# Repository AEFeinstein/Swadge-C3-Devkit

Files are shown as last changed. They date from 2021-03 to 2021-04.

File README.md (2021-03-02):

# Swadge-C3-Devkit

It's a Swadge devkit featuring:

* [ESP32-C3-MINI-1](https://www.espressif.com/sites/default/files/documentation/esp32-c3-mini-1_datasheet_en.pdf)
* [QMA6981 Accelerometer](https://datasheet.lcsc.com/szlcsc/QST-QMA6981_C310611.pdf)
* [0.96" 128x64 OLED Display](https://www.buydisplay.com/download/manual/ER-OLED0.96-1_Series_Datasheet.pdf)
* [Microphone](https://www.puiaudio.com/media/SpecSheet/POM-2738P-R.pdf)
* [Piezo Buzzer](https://datasheet.lcsc.com/szlcsc/1808301434_ZLFY-ZL-YDW1207-4005PA-5-0_C219727.pdf)
* 8x [WS2812b LEDs](https://cdn-shop.adafruit.com/datasheets/WS2812B.pdf)
* 8x [Tactile buttons](https://www.te.com/commerce/DocumentDelivery/DDEController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)
* 2x [AA Battery clips](http://www.keyelco.com/product-pdf.cfm?p=1025)
* [Micro USB Power](https://www.molex.com/pdm_docs/sd/473460001_sd.pdf)

It's compatible with the [Swadge Programmer](https://github.com/AEFeinstein/Super-2020-Swadge-HW/tree/master/hardware/swadge-programmer) used for ESP8266 based Swadges, though some GPIOs aren't broken out on the v2 programmer.

# 3D Render

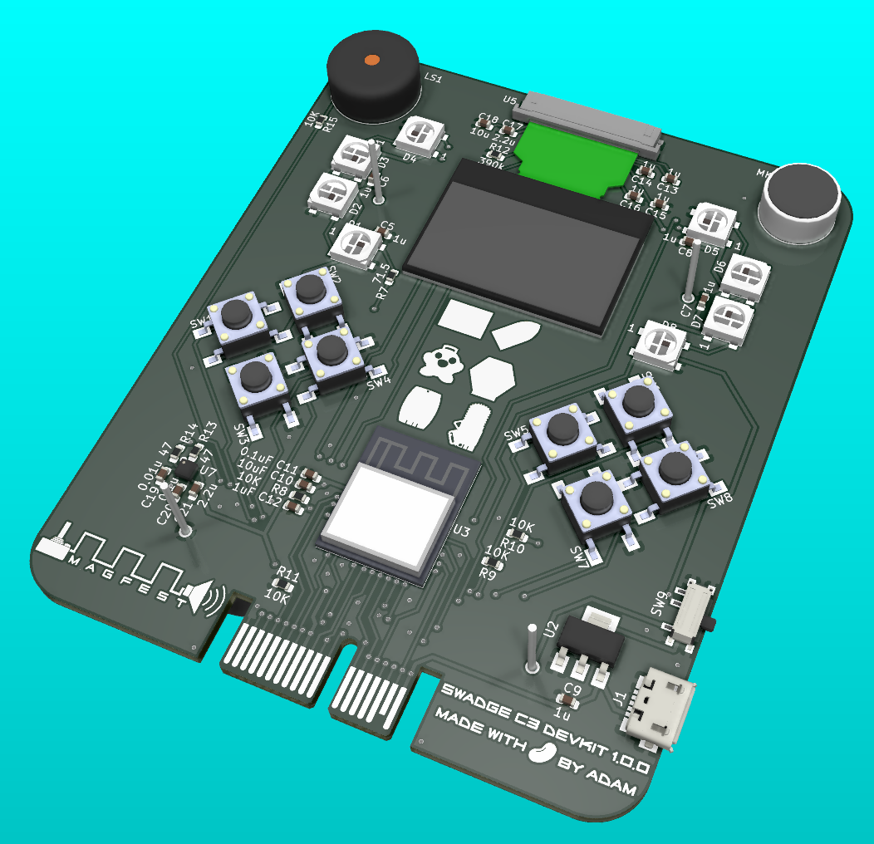
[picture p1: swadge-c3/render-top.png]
3D Render


# Schematic

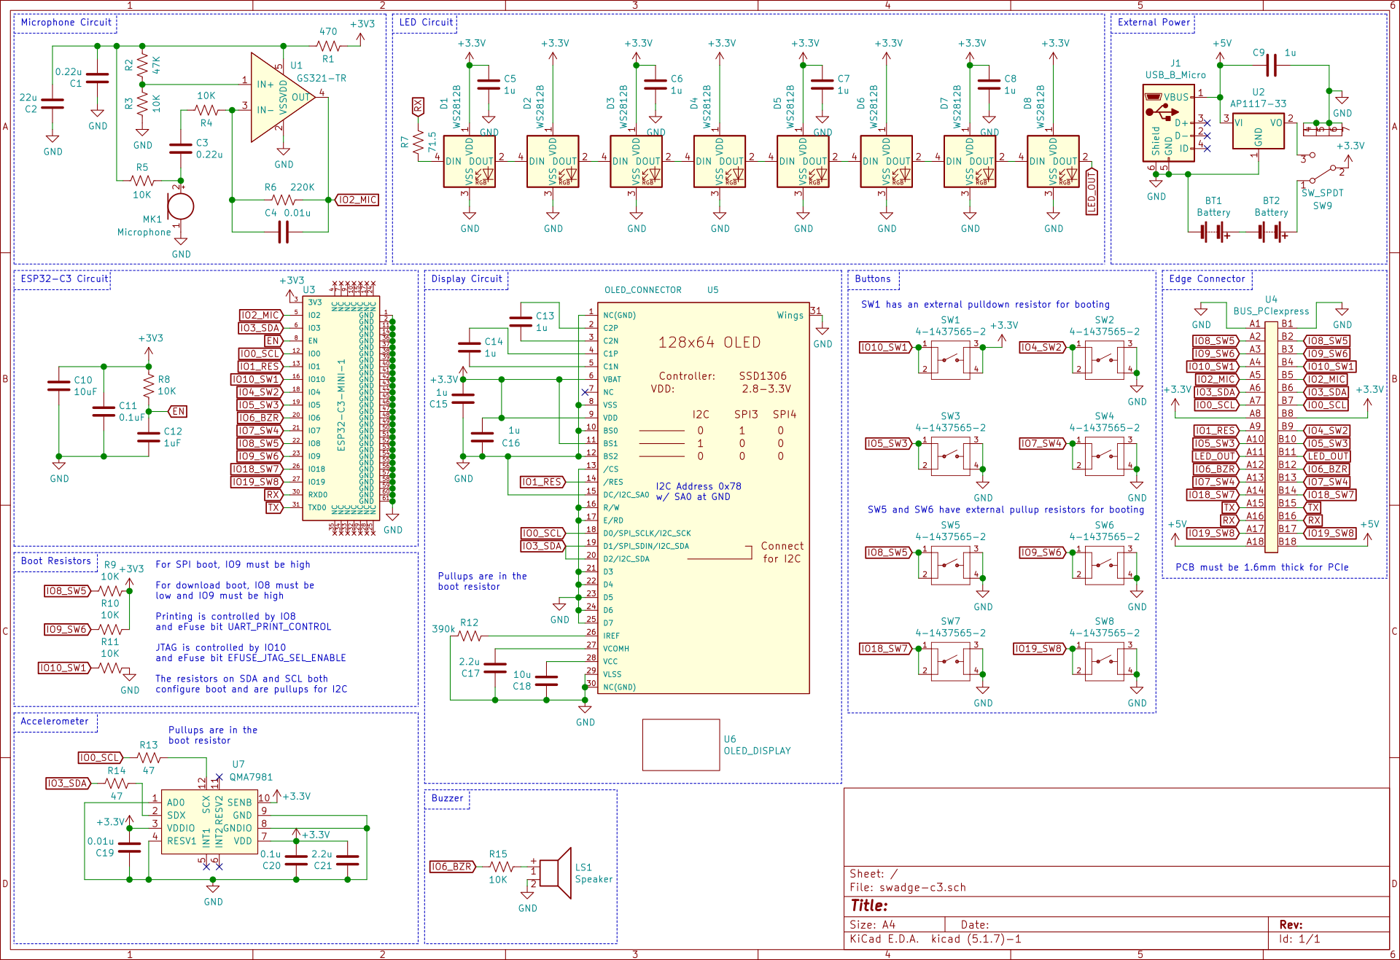
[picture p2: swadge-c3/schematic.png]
Schematic


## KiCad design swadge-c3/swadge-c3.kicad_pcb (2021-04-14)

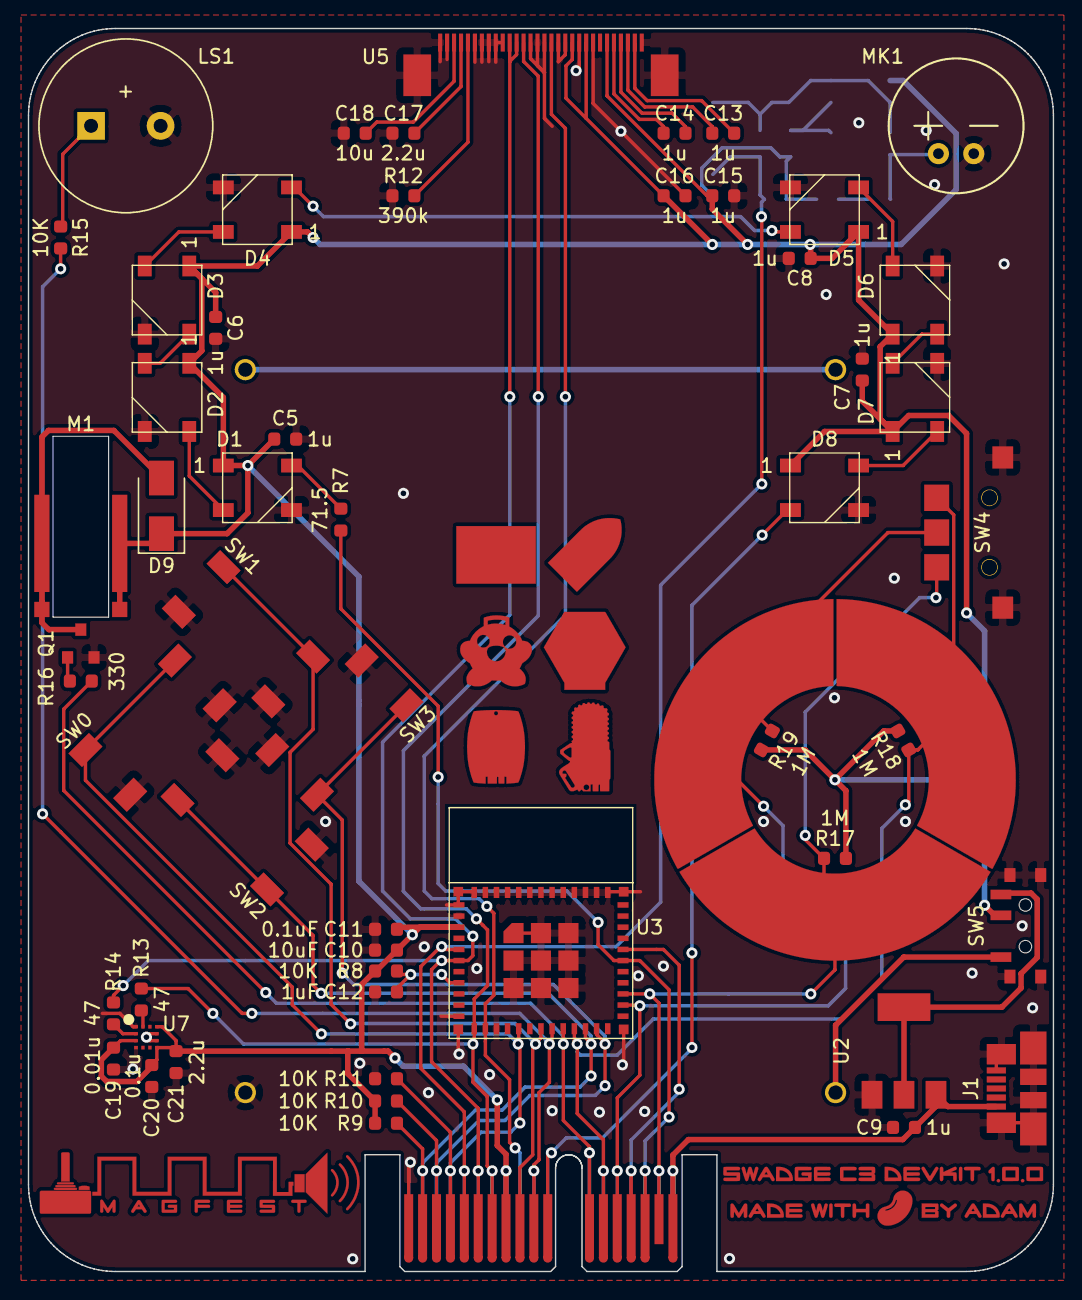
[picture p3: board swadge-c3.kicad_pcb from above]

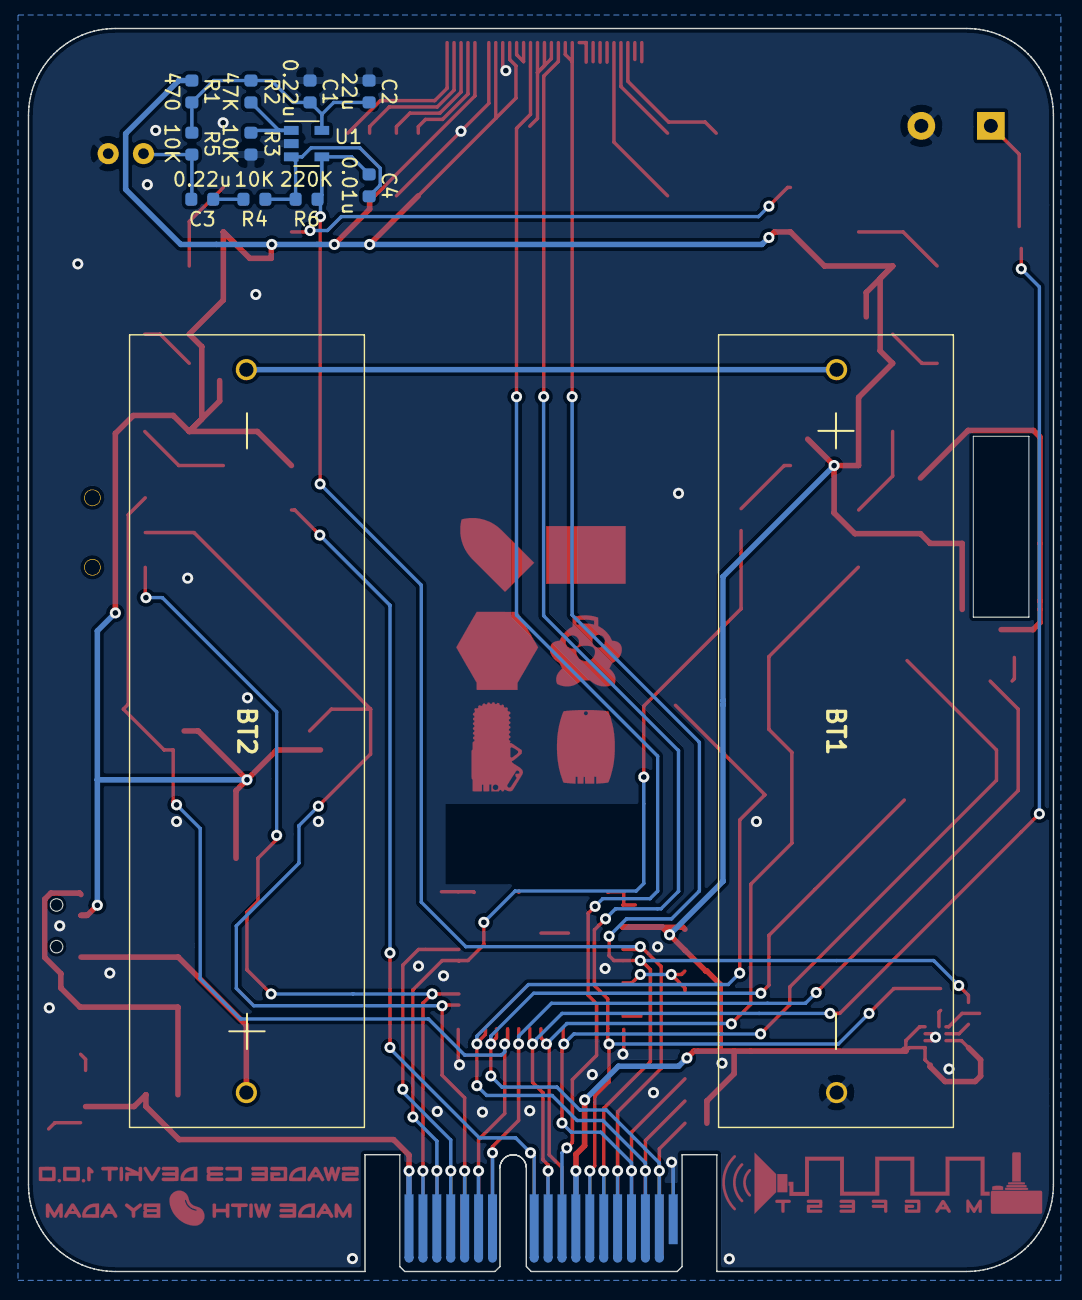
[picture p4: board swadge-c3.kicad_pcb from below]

Board: 2 copper layers, 73.7 x 89.4 mm, 73 parts (13 on the bottom side), 48 nets.

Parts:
BT1, BT2: Battery; 2460
C1, C3: 0.22u; C_0603_1608Metric
C2: 22u; C_0603_1608Metric
C4, C19: 0.01u; C_0603_1608Metric
C5, C6, C7, C8, C9, C13, C14, C15, C16: 1u; C_0603_1608Metric
C10: 10uF; C_0603_1608Metric
C11: 0.1uF; C_0603_1608Metric
C12: 1uF; C_0603_1608Metric
C17, C21: 2.2u; C_0603_1608Metric
C18: 10u; C_0603_1608Metric
C20: 0.1u; C_0603_1608Metric
D1, D2, D3, D4, D5, D6, D7, D8: WS2812B; LED_WS2812B_PLCC4_5.0x5.0mm_P3.2mm
D9: D; D_SMA
J1: USB_B_Micro; USB_Micro-B_Molex_47346-0001
LS1: Speaker; Buzzer_12.5x7.5
M1: Motor_DC; Z30C1B839982L
MK1: Microphone; CMA-4544PF-W
Q1: Q_NPN_BEC; SOT-23
R1: 470; R_0603_1608Metric
R2: 47K; R_0603_1608Metric
R3, R4, R5, R8, R9, R10, R11, R15: 10K; R_0603_1608Metric
R6: 220K; R_0603_1608Metric
R7: 71.5; R_0603_1608Metric
R12: 390k; R_0603_1608Metric
R13, R14: 47; R_0603_1608Metric
R16: 330; R_0603_1608Metric
R17, R18, R19: 1M; R_0603_1608Metric
SW0, SW1, SW2, SW3: 4-1437565-2; SW_4-1437565-2
SW4: LEVER8184
SW5: SW_SPDT; SW_SPDT_PCM12
TC1: touch-ring-3
U1: GS321-TR; SOT-23-5
U2: AP1117-33; SOT-223-3_TabPin2
U3: ESP32-C3-MINI-1; esp32-c2-mini-1
U4: BUS_PCIexpress
U5: OLED_CONNECTOR; ER-OLED0.96-1.3
U6: OLED_DISPLAY; NULL
U7: QMA7981; QMA6981
U8: art_made_by_adam; made-by-adam
U9: art_mag_logo_metal; mag-logo-metal
U10: art_swadge_family; swadges-family

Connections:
+3V3: C5.1, C6.1, C7.1, C8.1, C10.1, C11.1, C15.2, C16.2, C19.2, C20.2, C21.2, D1.1, D2.1, D3.1, D4.1, D5.1, D6.1, D7.1, D8.1, D9.1, M1.1, R1.1, R8.2, R9.1, R10.1, R17.2, R18.2, R19.2, SW5.2, U3.3, U4.A8, U4.B8, U5.6, U5.9, U5.11, U7.3, U7.7, U7.10
+5V: C9.2, J1.1, U2.3, U4.A18, U4.B18
EN: C12.1, R8.1, U3.8
GND: BT1.2, C1.1, C2.1, C5.2, C6.2, C7.2, C8.2, C9.1, C10.2, C11.2, C12.2, C15.1, C16.1, C17.1, C18.1, C19.1, C20.1, C21.1, D1.3, D2.3, D3.3, D4.3, D5.3, D6.3, D7.3, D8.3, J1.5, J1.6, LS1.2, MK1.1, Q1.2, R3.1, R11.1, R12.1, SW0.3, SW0.4, SW1.3, SW1.4, SW2.3, SW2.4, SW3.3, SW3.4, SW4.C, SW5.4, SW5.5, SW5.6, SW5.7, U1.2, U2.1, U3.1, U3.2, U3.11, U3.14, U3.36, U3.37, U3.38, U3.39, U3.40, U3.41, U3.42, U3.43, U3.44, U3.45, U3.46, U3.47, U3.48, U3.49, U3.50, U3.51, U3.52, U3.53, U3.54, U3.55, U3.56, U3.57, U3.58, U3.59, U3.60, U3.61, U4.A1, U4.B1, U5.1, U5.8, U5.10, U5.12, U5.13, U5.15, U5.16, U5.17, U5.21, U5.22, U5.23, U5.24, U5.25, U5.29, U5.30, U5.31, U7.1, U7.4, U7.8, U7.9
IO0_SCL: R13.2, U3.12, U4.A7, U4.B7, U5.18
IO1_RES: U3.13, U4.A9, U5.14
IO2_MIC: C4.1, R6.1, U1.4, U3.5, U4.A5, U4.B5
IO3_SDA: R14.2, U3.6, U4.A6, U4.B6, U5.19, U5.20
IO4_SW1: SW1.1, SW1.2, U3.18, U4.B9
IO5_BZR: R15.2, U3.19, U4.A10, U4.B10
IO6_VIB: R16.2, U3.20, U4.A12, U4.B12
IO7_TC0: R18.1, SW4.1, TC1.2, U3.21, U4.A13, U4.B13
IO8_SW2: R9.2, SW2.1, SW2.2, U3.22, U4.A2, U4.B2
IO9_SW3: R10.2, SW3.1, SW3.2, U3.23, U4.A3, U4.B3
IO10_SW0: R11.2, SW0.1, SW0.2, U3.16, U4.A4, U4.B4
IO18_TC1: R19.1, SW4.T, TC1.1, U3.26, U4.A14, U4.B14
IO19_TC2: R17.1, SW4.2, TC1.3, U3.27, U4.A17, U4.B17
LED_OUT: D8.2, U4.A11, U4.B11
unnamed: BT1.1, BT2.2
unnamed: BT2.1, SW5.1
unnamed: C1.2, C2.2, R1.2, R2.2, R5.1, U1.5
unnamed: C3.1, R4.2
unnamed: C3.2, MK1.2, R5.2
unnamed: C4.2, R4.1, R6.2, U1.3
unnamed: C13.1, U5.2
unnamed: C13.2, U5.3
unnamed: C14.1, U5.4
unnamed: C14.2, U5.5
unnamed: C17.2, U5.27
unnamed: C18.2, U5.28
unnamed: D1.2, D2.4
unnamed: D1.4, R7.1
unnamed: D2.2, D3.4
unnamed: D3.2, D4.4
unnamed: D4.2, D5.4
unnamed: D5.2, D6.4
unnamed: D6.2, D7.4
unnamed: D7.2, D8.4
unnamed: D9.2, M1.2, Q1.3
unnamed: LS1.1, R15.1
unnamed: Q1.1, R16.1
unnamed: R2.1, R3.2, U1.1
unnamed: R12.2, U5.26
unnamed: R13.1, U7.12
unnamed: R14.1, U7.2
unnamed: SW5.3, U2.2
RX: R7.2, U3.30, U4.A16, U4.B16
TX: U3.31, U4.A15, U4.B15

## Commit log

2021-02-26 Added CAD model for ESP32-C3-MINI-1
    [swadge-c3.kicad_pcb]
2021-02-26 Updated schematic
    [swadge-c3.kicad_pcb, swadge-c3.sch]
2021-02-27 Edited schematic, started layout
    [swadge-c3.kicad_pcb, swadge-c3.sch]
2021-02-27 layout updates
    [swadge-c3.kicad_pcb, swadge-c3.sch]
2021-03-01 Update layout
    [swadge-c3.kicad_pcb]
2021-03-01 Complete PCB routing
    [swadge-c3.kicad_pcb]
2021-03-01 Rounded corners
    [swadge-c3.kicad_pcb]
2021-03-01 Fix alignment
    [swadge-c3.kicad_pcb]
2021-03-02 Added art, renders, exported schematic
    [swadge-c3.kicad_pcb]
2021-03-02 Use correct schematic
2021-03-02 Replace SVG schematic with PNG
2021-03-02 Replaced QMA6981 with QMA7981. Updated art. Updated renders
    [swadge-c3.kicad_pcb, swadge-c3.sch]
2021-03-07 Added three way thumbswitch
    [swadge-c3.kicad_pcb, swadge-c3.sch]
2021-03-22 Replaced four left buttons with scrollwheel
    [swadge-c3.kicad_pcb, swadge-c3.sch]
2021-03-22 Added pullups
    [swadge-c3.kicad_pcb, swadge-c3.sch]
2021-04-14 Added diode, vib motor, touch ring
    [swadge-c3.kicad_pcb, swadge-c3.sch]
2021-04-14 Fixed touch ring, added art
    [swadge-c3.kicad_pcb]
2021-04-14 Update vibration motor CAD
    [swadge-c3.kicad_pcb]
2021-04-14 Added parts for art
    [swadge-c3.kicad_pcb, swadge-c3.sch]
2021-04-14 Move around resistors, silk
    [swadge-c3.kicad_pcb]
